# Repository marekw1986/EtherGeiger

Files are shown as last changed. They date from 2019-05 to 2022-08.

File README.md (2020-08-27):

# EtherGeiger

## Overview

This is firmware for Ethergeiger project, described on my [Hackaday.io profile](https://hackaday.io/project/163717-ethergeiger-20).

## Required Tools

Project was created in Microchip MPLAB X IDE.

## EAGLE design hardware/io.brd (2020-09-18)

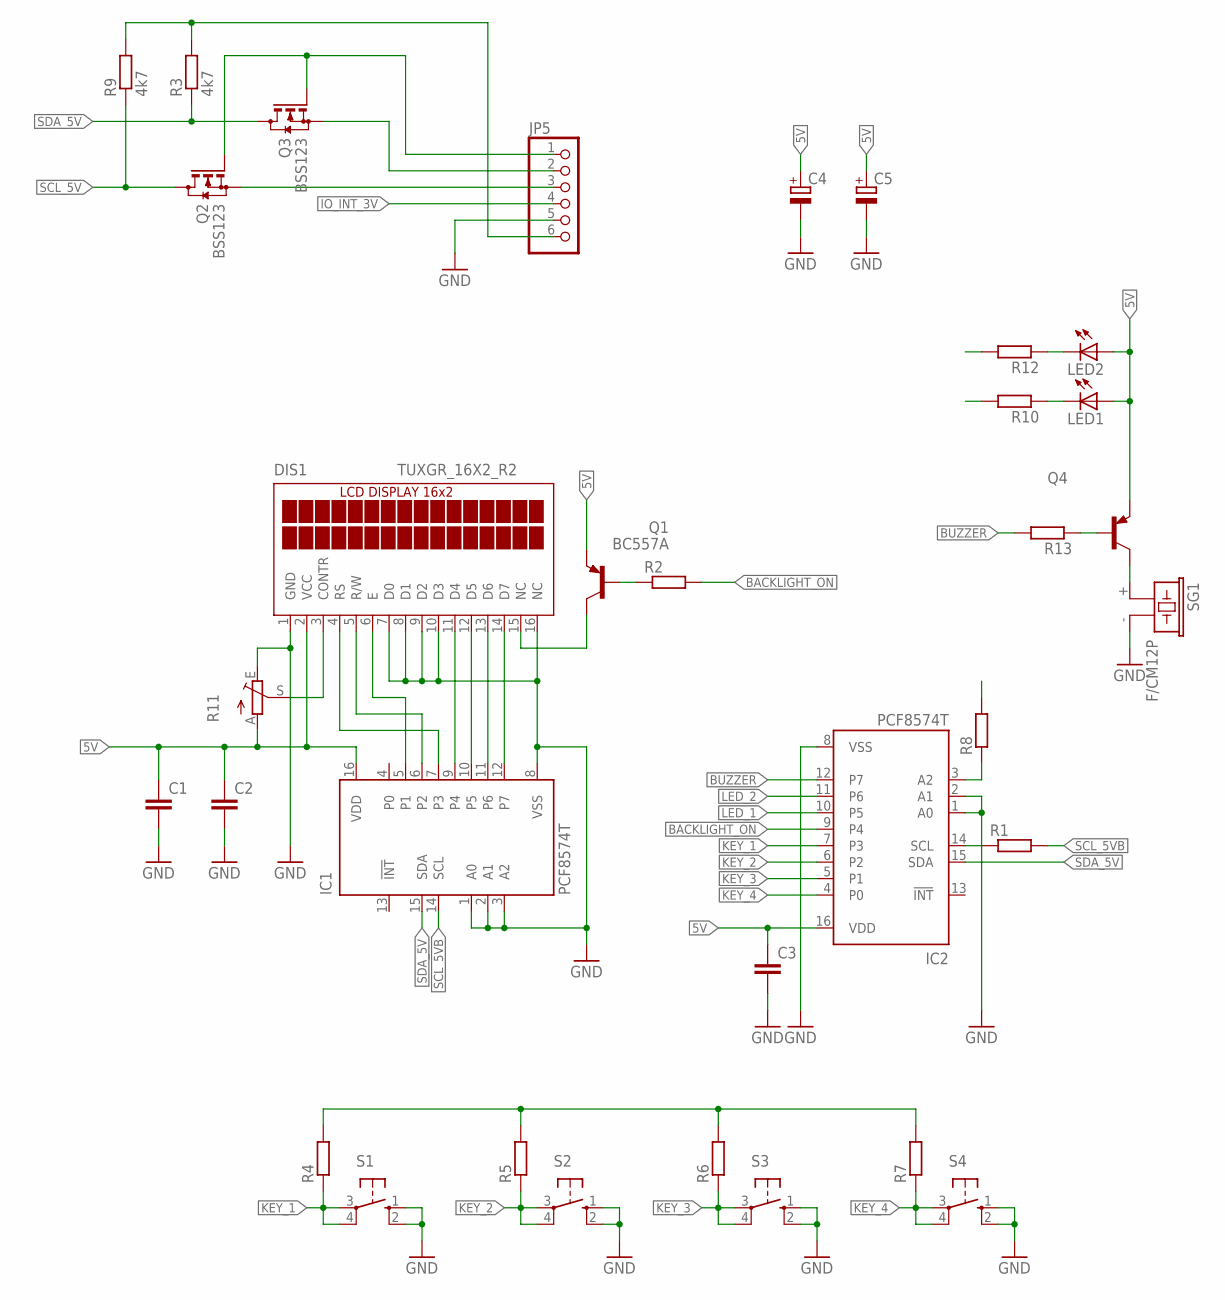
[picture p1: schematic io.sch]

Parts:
C1, C3: C-EUC1206; C1206
C2: C-EUC0603; C0603
C4, C5: CPOL-EUSMCD; SMC_D
DIS1: TUXGR_16X2_R2
IC1, IC2: PCF8574T; SO16W
JP5: PINHD-1X6; 1X06
LED1, LED2: LED5MM
Q1: BC557A; TO92-EBC
Q2, Q3: BSS123; SOT23
Q4: BC557A-PNP-TO92-EBC; TO92-EBC
R1, R8, R13: R-EU_R0603; R0603
R2, R6, R7, R10, R12: R-EU_0204/5; 0204/5
R3: 4k7; R0603
R4, R5: R-EU_0204/7; 0204/7
R9: 4k7; R1206
R11: TRIM_EU-B25U; B25U
S1, S2, S3, S4: 10-XX; B3F-10XX
SG1: F/CM12P

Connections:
5V: C1.1, C2.1, C3.1, C4.+, C5.+, DIS1.2 (VCC), IC1.16 (VDD), IC2.16 (VDD), JP5.6, LED1.A, LED2.A, Q1.E, Q4.E, R3.2, R4.2, R5.2, R6.2, R7.2, R8.2, R9.2, R11.A
BACKLIGHT_ON: IC2.9 (P4), R2.2
BUZZER: IC2.12 (P7), R13.2
GND: C1.2, C2.2, C3.2, C4.-, C5.-, DIS1.1 (GND), DIS1.7 (D0), DIS1.8 (D1), DIS1.9 (D2), DIS1.10 (D3), DIS1.16 (NC), IC1.1 (A0), IC1.2 (A1), IC1.3 (A2), IC1.8 (VSS), IC2.1 (A0), IC2.2 (A1), IC2.8 (VSS), JP5.5, R11.E, S1.1 (S), S1.2 (S1), S2.1 (S), S2.2 (S1), S3.1 (S), S3.2 (S1), S4.1 (S), S4.2 (S1), SG1.- (2)
IO_INT_3V: JP5.4
KEY_1: IC2.7 (P3), R4.1, S1.3, S1.4 (P1)
KEY_2: IC2.6 (P2), R5.1, S2.3, S2.4 (P1)
KEY_3: IC2.5 (P1), R6.1, S3.3, S3.4 (P1)
KEY_4: IC2.4 (P0), R7.1, S4.3, S4.4 (P1)
LED_1: IC2.10 (P5), R10.2
LED_2: IC2.11 (P6), R12.2
unnamed: DIS1.14 (D7), IC1.12 (P7)
unnamed: DIS1.13 (D6), IC1.11 (P6)
unnamed: DIS1.12 (D5), IC1.10 (P5)
unnamed: DIS1.11 (D4), IC1.9 (P4)
unnamed: DIS1.6 (E), IC1.5 (P1)
unnamed: DIS1.5 (R/W), IC1.6 (P2)
unnamed: DIS1.4 (RS), IC1.7 (P3)
unnamed: IC2.3 (A2), R8.1
unnamed: DIS1.15 (NC), Q1.C
unnamed: Q1.B, R2.1
unnamed: DIS1.3 (CONTR), R11.S
unnamed: LED1.K (C), R10.1
unnamed: LED2.K (C), R12.1
unnamed: Q4.C, SG1.+ (1)
unnamed: Q4.B, R13.1
SCL_3V: JP5.3, Q2.2 (S)
SCL_5V: IC2.14 (SCL), Q2.3 (D), R1.1, R9.1
SCL_5VB: IC1.14 (SCL), R1.2
SDA_3V: JP5.2, Q3.2 (S)
SDA_5V: IC1.15 (SDA), IC2.15 (SDA), Q3.3 (D), R3.1
_3V: JP5.1, Q2.1 (G), Q3.1 (G)

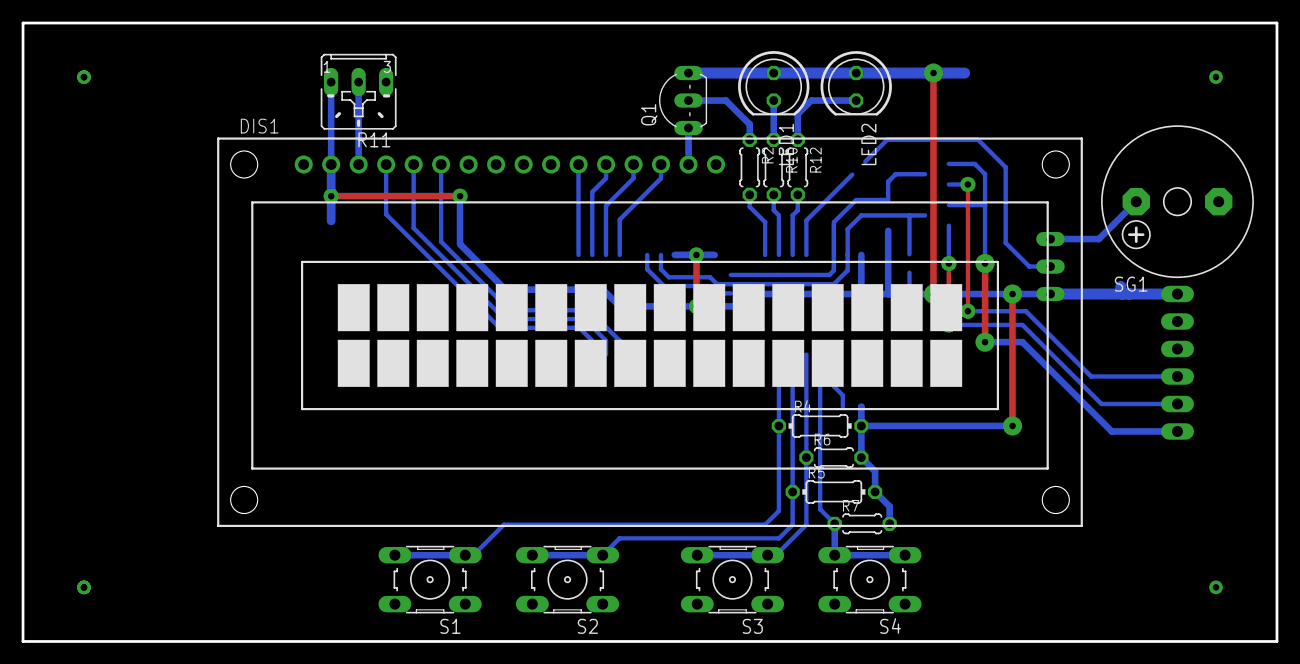
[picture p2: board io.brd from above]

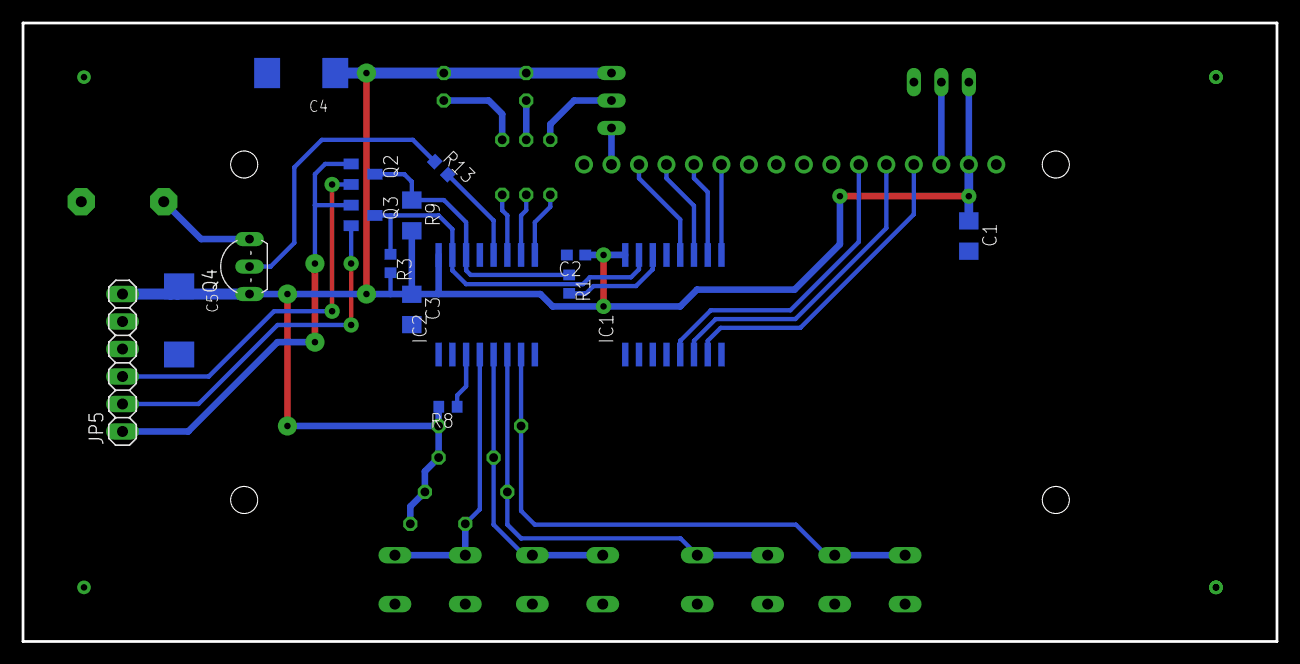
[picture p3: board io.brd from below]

Board: 2 copper layers, 115.9 x 57.1 mm, 33 parts (16 on the bottom side), 31 nets.

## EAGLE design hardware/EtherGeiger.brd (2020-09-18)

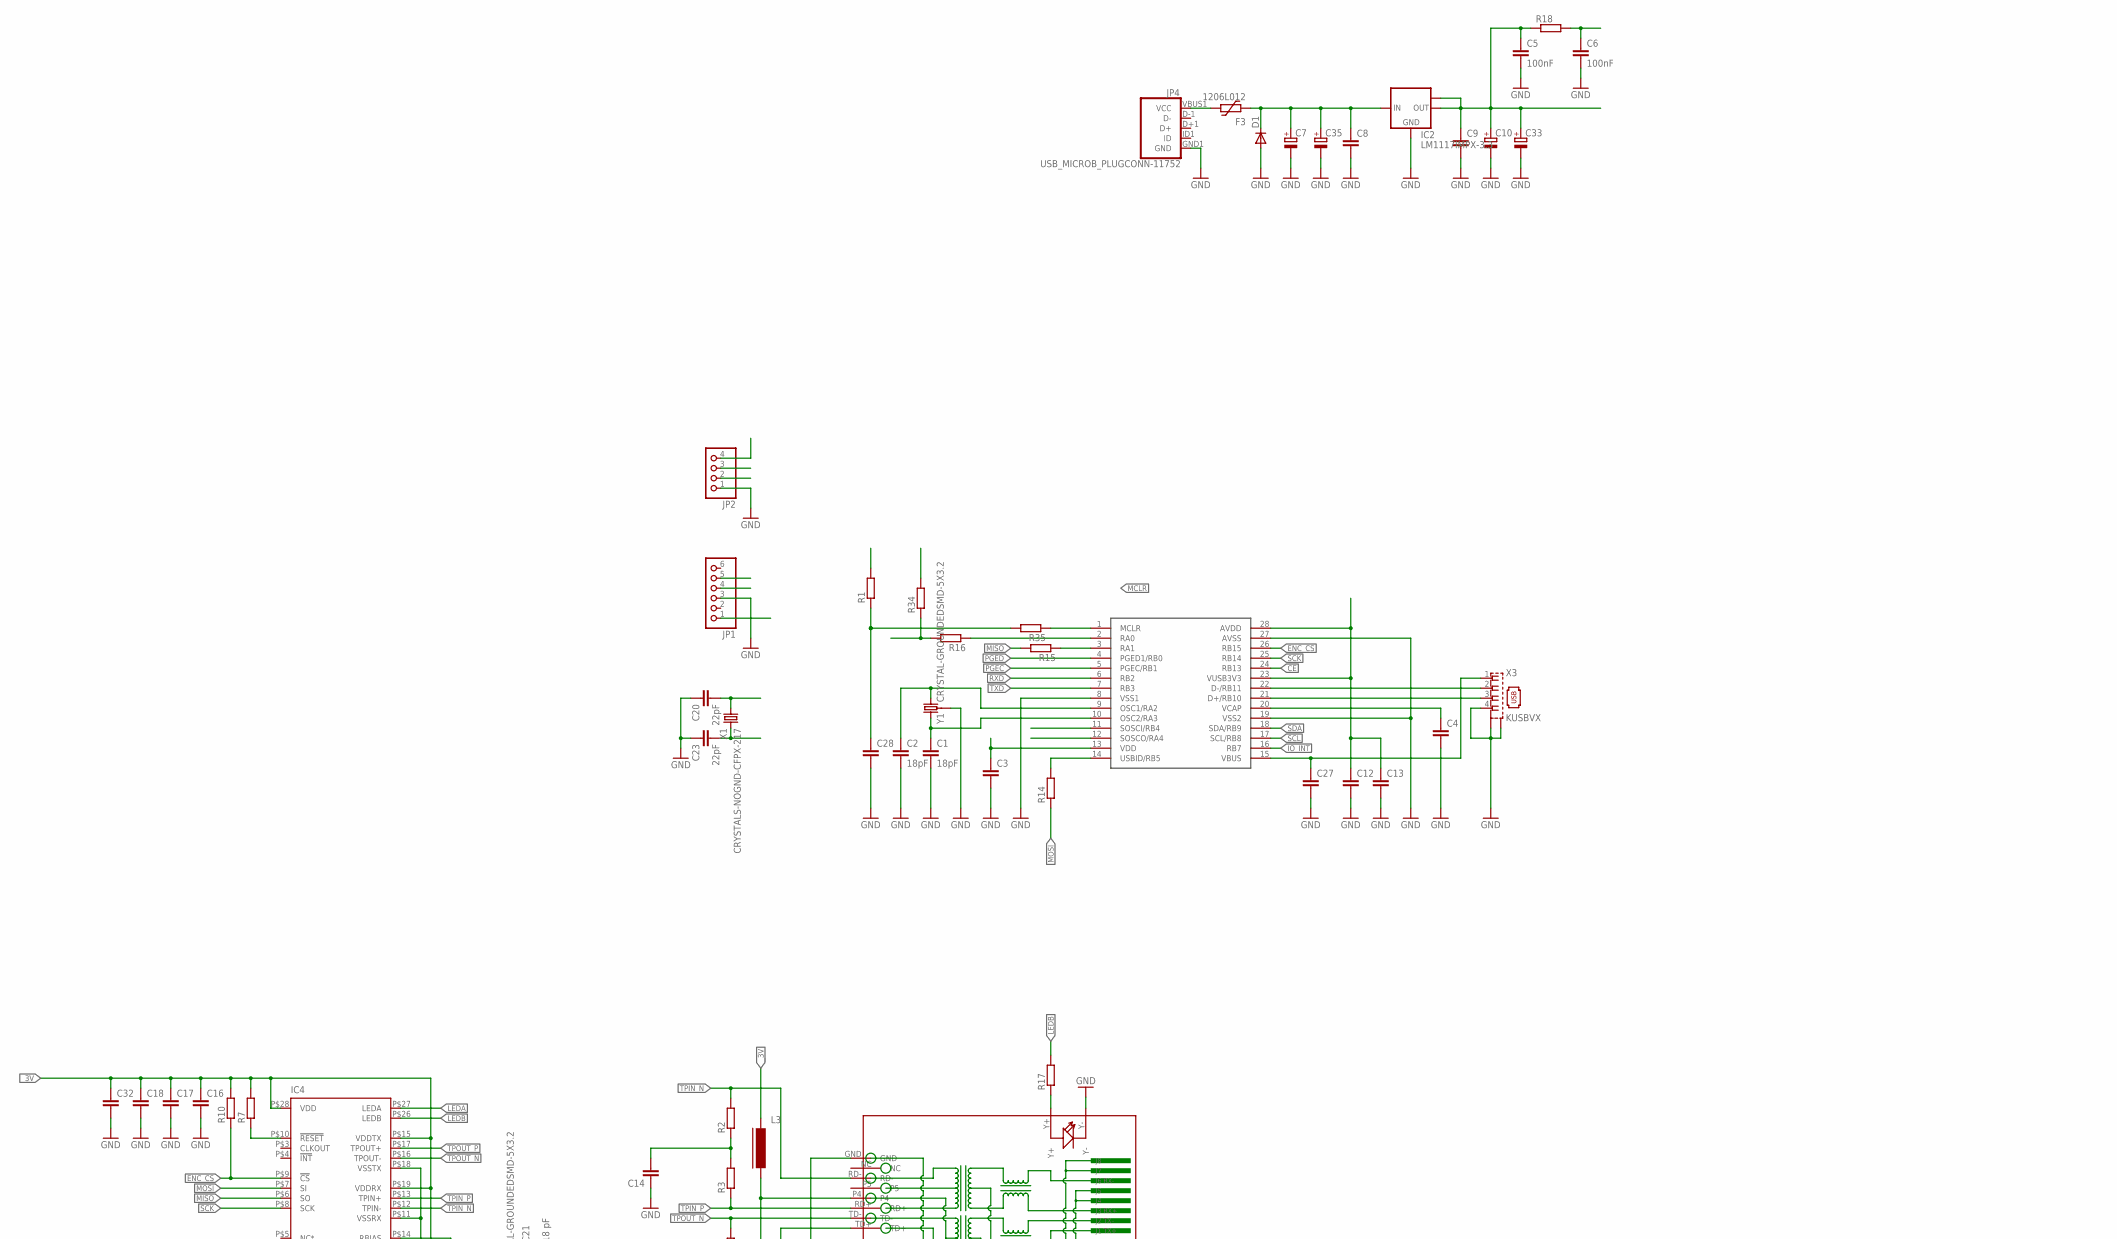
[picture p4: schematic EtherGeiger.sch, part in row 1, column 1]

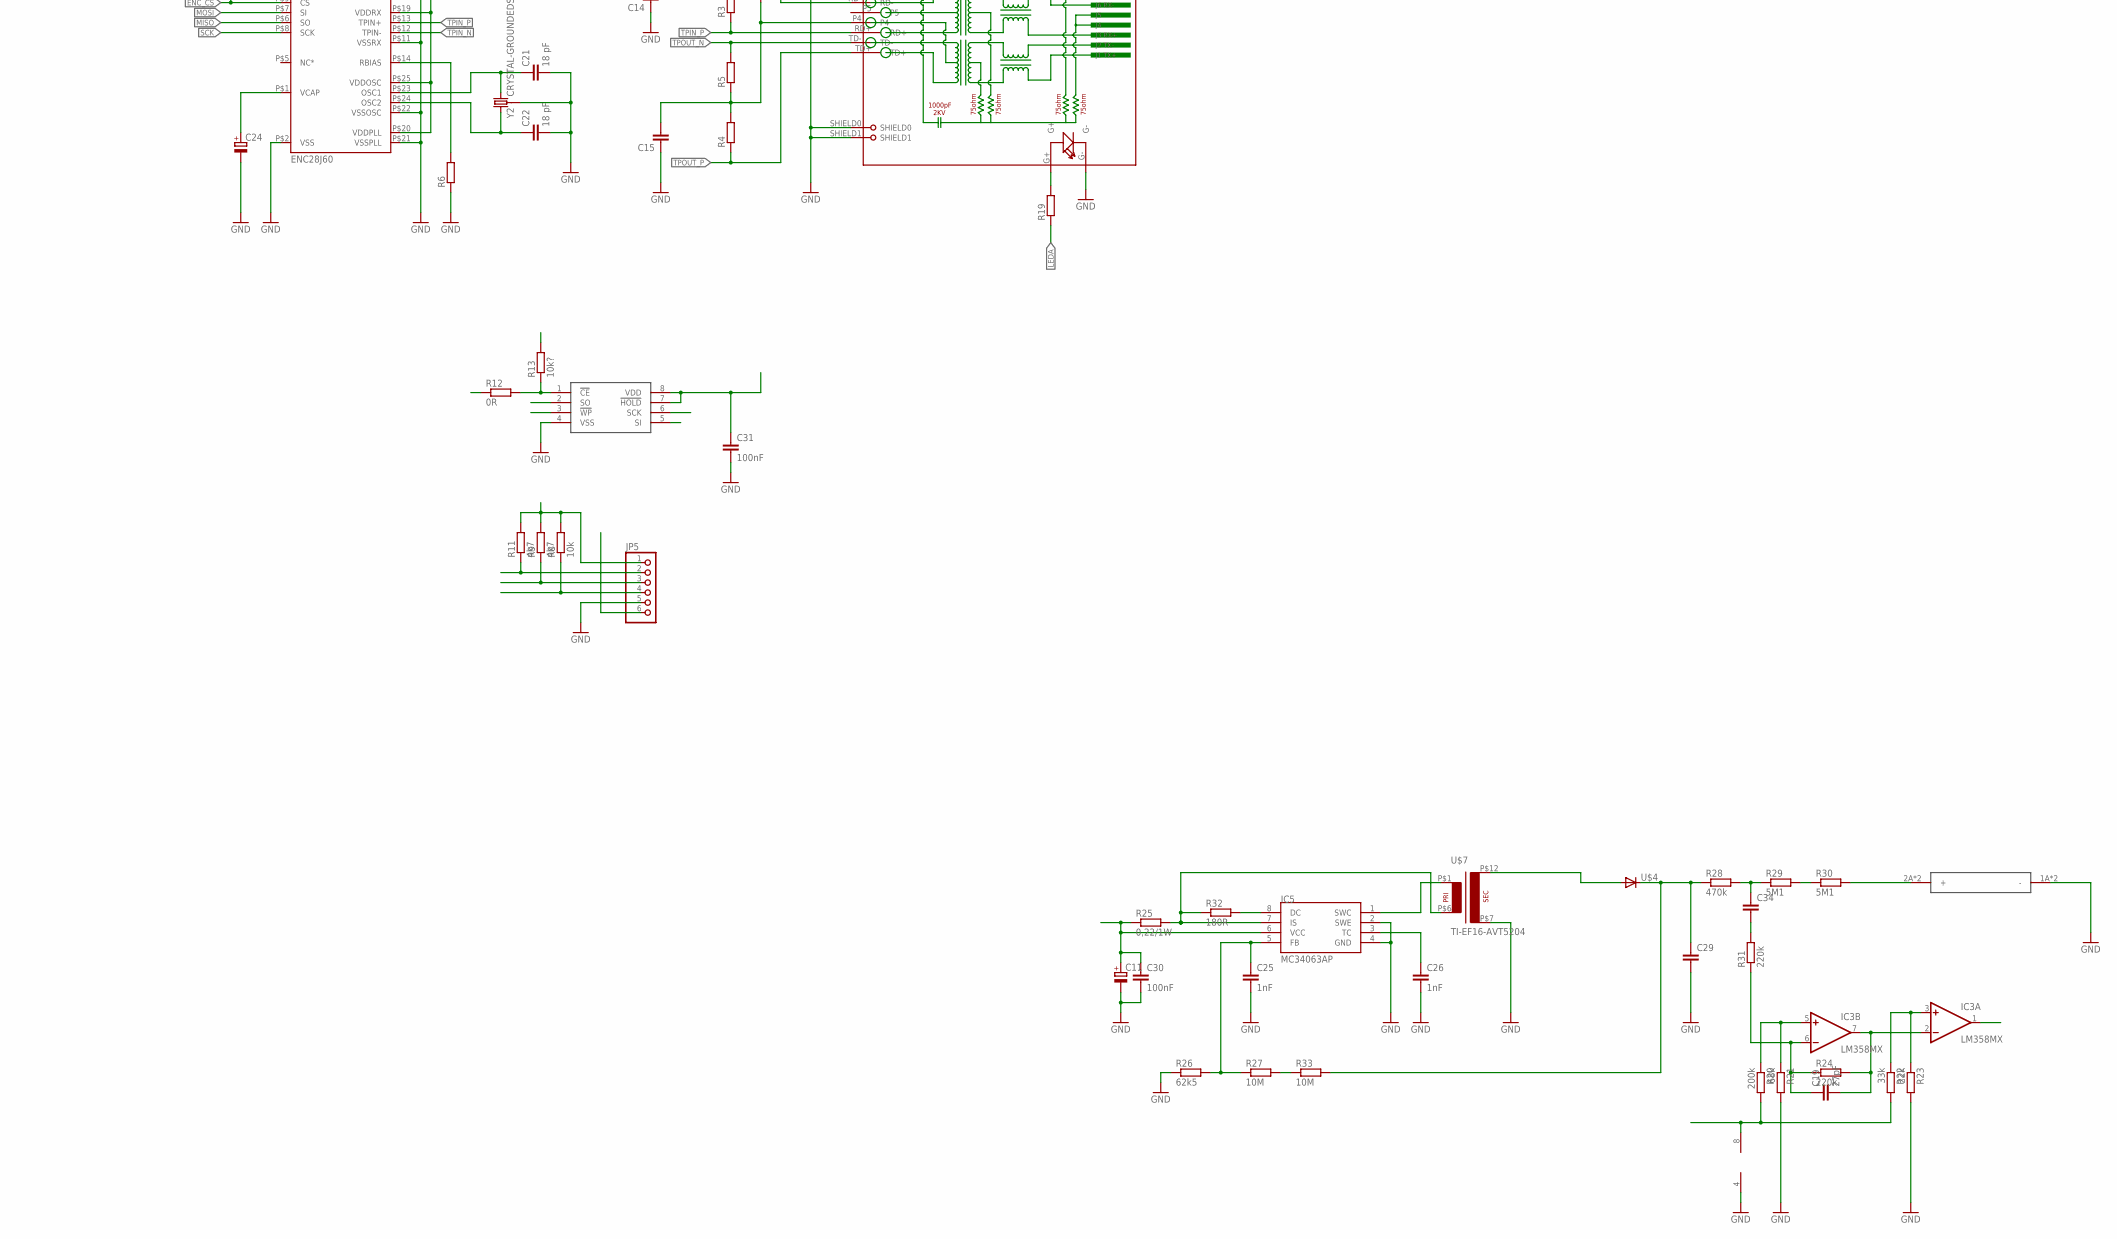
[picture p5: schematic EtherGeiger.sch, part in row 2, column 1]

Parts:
C1, C2: 18pF; C0603
C3, C12, C16, C32: C-EUC0402; C0402
C4, C8, C9, C13, C14, C15, C17, C18, C27, C28: C-EUC0603; C0603
C5, C6, C30, C31: 100nF; C0603
C7: CPOL-EUSMCC; SMC_C
C10: CPOL-EUSMCB; SMC_B
C11: CPOL-EUSMCE; SMC_E
C19: 27pF; C0603
C20, C23: 22pF; C0603
C21, C22: 18 pF; C0603
C24, C33, C35: CPOL-EUSMCA; SMC_A
C25, C26: 1nF; C0603
C29: C-EU225-113X268; C225-113X268
C34: C-EU050-024X044; C050-024X044
D1: DIODE-SMB; SMB
F3: 1206L012; 1206L
IC2: LM1117IMPX-3.3; SOT223
IC3: LM358MX; SO08
IC4: ENC28J60; TSSOP28W
IC5: MC34063AP; DIL08
JP1, JP5: PINHD-1X6; 1X06
JP2: PINHD-1X4; 1X04
JP4: USB_MICROB_PLUGCONN-11752; USB-B-MICRO-SMD_V03
L3: FERRITE-0805; FB805
R1, R2, R3, R4, R5, R7, R10, R14, R15, R34, R35: R-EU_R0603; R0603
R6: R-EU_R0805; R0805
R8: 10k; R0402
R9, R11: 4k7; R0402
R12: 0R; R0603
R13: 10k?; R0603
R16, R17, R18, R19: R-EU_R1206; R1206
R20: 200k; R0603
R21: 68k; R0603
R22: 33k; R0603
R23: 22k; R0603
R24: 220k; R0603
R25: 0,22/1W; R2010
R26: 62k5; R1206
R27, R33: 10M; R2512
R28: 470k; R2512
R29, R30: 5M1; R2512
R31: 220k; M1206
R32: 180R; R0805
RJ1: HR911105A
U$1: PIC32MX250F128B2; SSOP28
U$2: SST25VF016BSO8M; SO-08M
U$4: DIODE-MELF-MLL41; MELF-MLL41
U$5: STS5; GEIGERTUBE
U$7: TI-EF16-AVT5204; EF16-K-H-12P-12,5
X1: CRYSTALS-NOGND-CFPX-217; 3.2X1.5-2-PAD
X3: KUSBVX
Y1, Y2: CRYSTAL-GROUNDEDSMD-5X3.2; CRYSTAL-SMD-5X3.2-4PAD

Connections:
A_3V: C6.1, IC3.8 (V+), R18.2, R20.2, R22.2
CE: R12.1, U$1.24 (RB13)
CE1: R12.2, R13.1, U$2.1 (!CE)
CPM: IC3.1 (OUT), R16.2, R34.1
D_N: U$1.22 (D-/RB11), X3.2
D_P: U$1.21 (D+/RB10), X3.3
ENC_CS: IC4.P$9 (!CS), R10.1, U$1.26 (RB15)
ENC_RST: IC4.P$10 (!RESET), R7.1
GND: C1.2, C2.2, C3.2, C4.2, C5.2, C6.2, C7.-, C8.2, C9.2, C10.-, C11.-, C12.2, C13.2, C14.1, C15.1, C16.2, C17.2, C18.2, C20.1, C21.2, C22.2, C23.1, C24.-, C25.2, C26.2, C27.2, C28.2, C29.2, C30.2, C31.2, C32.2, C33.-, C35.-, D1.A, IC2.1 (GND), IC3.4 (V-), IC4.P$2 (VSS), IC4.P$11 (VSSRX), IC4.P$18 (VSSTX), IC4.P$21 (VSSPLL), IC4.P$22 (VSSOSC), IC5.2 (SWE), IC5.4 (GND), JP1.3, JP2.1, JP4.GND1 (GND), JP5.5, R6.1, R21.2, R23.2, R26.1, RJ1.G-, RJ1.GND, RJ1.SHIELD0, RJ1.SHIELD1, RJ1.Y-, U$1.8 (VSS1), U$1.19 (VSS2), U$1.27 (AVSS), U$2.4 (VSS), U$5.1A (-), U$5.1B (-), U$7.P$7 (P7), X3.4, X3.M1 (S1), X3.M2 (S2), Y1.2 (3), Y1.4 (3), Y2.2 (3), Y2.4 (3)
HV: C29.1, R28.1, R33.2, U$4.C
IO_INT: JP5.4, R8.1, U$1.16 (RB7)
LEDA: IC4.P$27 (LEDA), R19.1
LEDB: IC4.P$26 (LEDB), R17.2
MCLR: JP1.1, R35.1, U$1.1 (MCLR)
MISO: IC4.P$6 (SO), R15.2, U$2.2 (SO)
MOSI: IC4.P$7 (SI), R14.1, U$2.5 (SI)
unnamed: C14.2, R2.1, R3.2
unnamed: IC5.7 (IS), R25.2, R32.1, U$7.P$6 (P6)
unnamed: C19.1, IC3.6 (-IN), R24.1, R31.1
unnamed: C15.2, L3.2, R4.2, R5.1, RJ1.P4
unnamed: C4.1, U$1.20 (VCAP)
unnamed: C19.2, IC3.2 (-IN), IC3.7 (OUT), R24.2
unnamed: C26.1, IC5.3 (TC)
unnamed: IC4.P$14 (RBIAS), R6.2
unnamed: R14.2, U$1.14 (USBID/RB5)
unnamed: F3.1, JP4.VBUS1 (VCC)
unnamed: R15.1, U$1.3 (RA1)
unnamed: R16.1, U$1.2 (RA0)
unnamed: C1.1, U$1.10 (OSC2/RA3), Y1.3 (1)
unnamed: C2.1, U$1.9 (OSC1/RA2), Y1.1 (2)
unnamed: IC3.5 (+IN), R20.1, R21.1
unnamed: IC3.3 (+IN), R22.1, R23.1
unnamed: U$4.A, U$7.P$12 (P12)
unnamed: C21.1, IC4.P$23 (OSC1), Y2.1 (2)
unnamed: C22.1, IC4.P$24 (OSC2), Y2.3 (1)
unnamed: C25.1, IC5.5 (FB), R26.2, R27.1
unnamed: R30.2, U$5.2A (+), U$5.2B (+)
unnamed: R29.2, R30.1
unnamed: C34.1, R28.2, R29.1
unnamed: C34.2, R31.2
unnamed: C24.+, IC4.P$1 (VCAP)
unnamed: R17.1, RJ1.Y+
unnamed: R19.2, RJ1.G+
unnamed: IC5.1 (SWC), U$7.P$1 (P1)
unnamed: IC5.8 (DC), R32.2
unnamed: R27.2, R33.1
PGEC: JP1.5, U$1.5 (PGEC/RB1)
PGED: JP1.4, U$1.4 (PGED1/RB0)
RXD: JP2.3, U$1.6 (RB2)
SCK: IC4.P$8 (SCK), U$1.25 (RB14), U$2.6 (SCK)
SCL: JP5.3, R9.1, U$1.17 (SCL/RB8)
SDA: JP5.2, R11.1, U$1.18 (SDA/RB9)
SOSCI: C20.2, U$1.11 (SOSCI/RB4), X1.1
SOSCO: C23.2, U$1.12 (SOSCO/RA4), X1.2
TPIN_N: IC4.P$12 (TPIN-), R2.2, RJ1.RD-
TPIN_P: IC4.P$13 (TPIN+), R3.1, RJ1.RD+
TPOUT_N: IC4.P$16 (TPOUT-), R5.2, RJ1.TD-
TPOUT_P: IC4.P$17 (TPOUT+), R4.1, RJ1.TD+
TXD: JP2.2, U$1.7 (RB3)
VBUS: C7.+, C8.1, C11.+, C27.1, C30.1, C35.+, D1.C, F3.2, IC2.3 (IN), IC5.6 (VCC), JP5.6, R25.1, U$1.15 (VBUS), X3.1
_3V: C3.1, C5.1, C9.1, C10.+, C12.1, C13.1, C16.1, C17.1, C18.1, C31.1, C32.1, C33.+, IC2.2 (OUT), IC2.TAB (OUT1), IC4.P$15 (VDDTX), IC4.P$19 (VDDRX), IC4.P$20 (VDDPLL), IC4.P$25 (VDDOSC), IC4.P$28 (VDD), JP2.4, JP5.1, L3.1, R1.2, R7.2, R8.2, R9.2, R10.2, R11.2, R13.2, R18.1, R34.2, U$1.13 (VDD), U$1.23 (VUSB3V3), U$1.28 (AVDD), U$2.3 (!WP), U$2.7 (!HOLD), U$2.8 (VDD)
_MCLR: C28.1, R1.1, R35.2

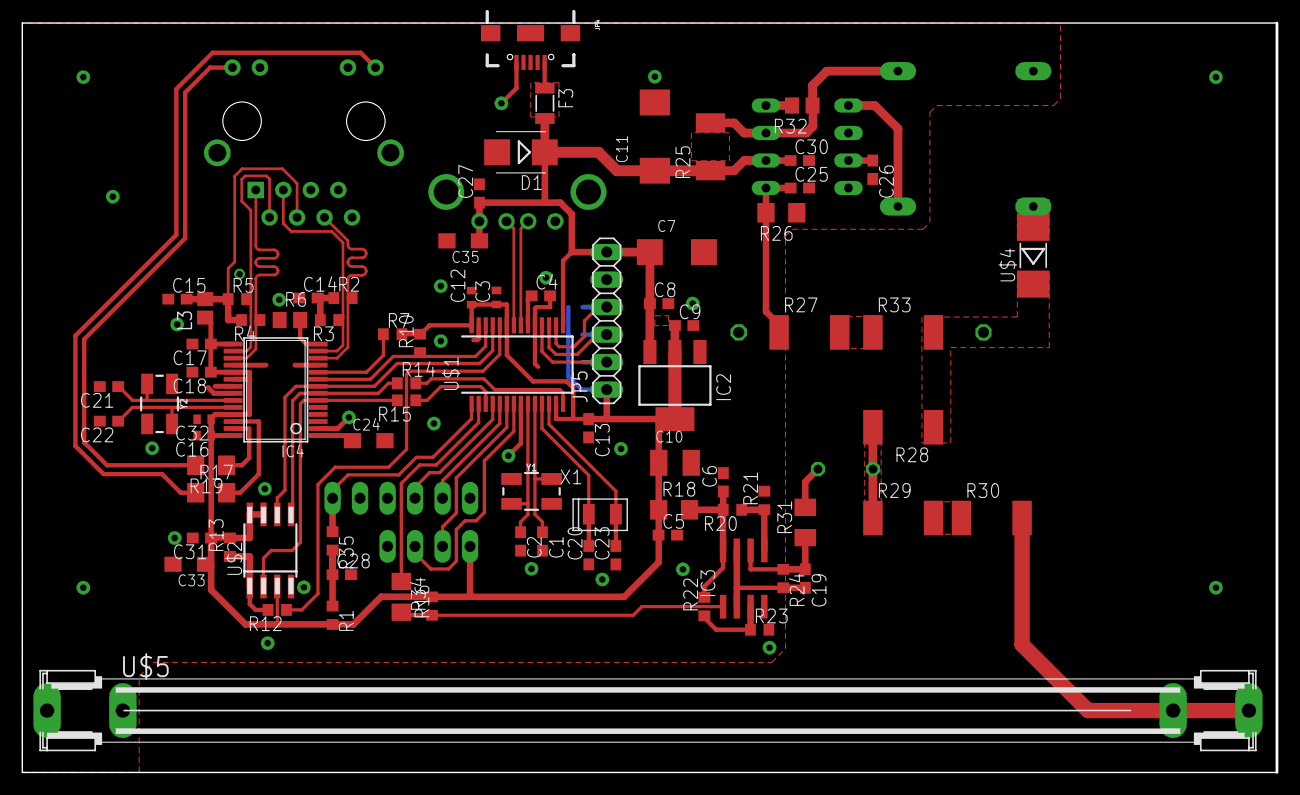
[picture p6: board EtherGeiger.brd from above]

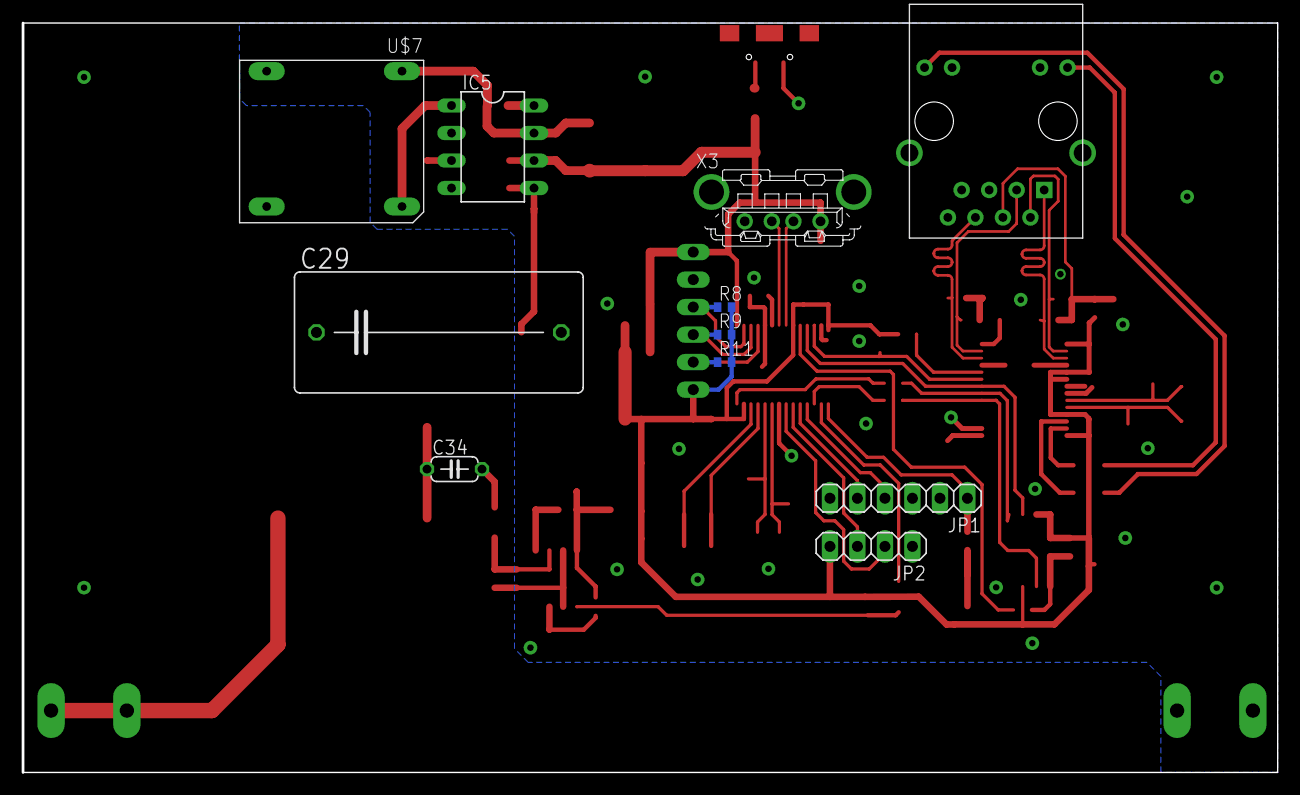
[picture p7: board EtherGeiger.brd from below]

Board: 2 copper layers, 115.9 x 69.2 mm, 91 parts (11 on the bottom side), 62 nets.

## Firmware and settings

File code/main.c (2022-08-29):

/* 
 * File:   main.c
 * Author: Marek
 *
 * Created on 7 stycznia 2016, 12:22
 */

#include <xc.h>
#include <stdio.h>
#include <stdlib.h>
#include <stdint.h>
#include <p32xxxx.h>
#include <plib.h>
#include <time.h>
#include <string.h>

#include "delay/delay.h"
#include "time/time.h"
#include "uart/uart.h"
#include "common.h"
#include "usb_host_msd/usb.h"
#include "usb_host_msd/usb_host_msd.h"
#include "usb_host_msd/usb_host_msd_scsi.h"
#include "fatfs/ff.h"
#include "fatfs/diskio.h"
#include "net/TCPIP.h"
#include "net/MQTT.h"
#include "nvram/nvram.h"
#include "config/config.h"
#include "geiger/geiger.h"
#include "HardwareProfile.h"
#include "lcd/i2c.h"
#include "lcd/hd44780.h"
#include "bme280/bme280.h"


#pragma config JTAGEN = OFF        // Disable JTAG
#pragma config FSOSCEN = ON        // ENABLE secondary oscillator

#pragma config POSCMOD=HS          // High speed crystal mode
#pragma config FNOSC=PRIPLL        // Use Primary Oscillator with PLL (XT, HS, or EC) 
#pragma config FPLLIDIV=DIV_2      // Divide 8MHz to between 4-5MHz before PLL (now 4MHz)
#pragma config FPLLMUL=MUL_20      // Multiply with PLL (now 80MHz)
#pragma config FPLLODIV=DIV_2      // Divide After PLL (now 40 MHz)

#pragma config FWDTEN = ON         // Enable watchdog timer
#pragma config WDTPS = PS4096
#pragma config ICESEL = ICS_PGx1   // select pins to transfer program data on (ICSP pins)

#pragma config FVBUSONIO = OFF
#pragma config FUSBIDIO = OFF
#pragma config UPLLEN   = ON
#pragma config UPLLIDIV = DIV_2

char buffer[128];
FATFS SPIFatFS;
FATFS USBFatFS;

extern void GenericTCPServer(void);
static void handle_usb_log (void);
static void handle_bme_read (void);
//void handle_mqtt(void);
char* constructJSON (char* buf, uint16_t len);
void mqtt_init (void);
void handle_mqtt_log(void);
void mqtt_on_connect(void);
void mqtt_on_publish(void);
void mqtt_on_subscribe(void);
void mqtt_on_receive(const char *topic, const WORD topicLength, const BYTE *payload, const WORD payloadLength);

int main(int argc, char** argv) {
    
    FRESULT res;
    uint32_t disk_timer, wdt_timer;
    uint8_t io;
    
    DisableWDT();
    SYSTEMConfigPerformance(SYSCLK);
    
    __XC_UART = 1;
    
    ANSELA = 0;
    ANSELB = 0;
    TRISBbits.TRISB15 = 0;      //ENC28J60 CS
    
    SDI1Rbits.SDI1R = 0b0000; 	//SDI1 is RPA1
    RPB5Rbits.RPB5R = 0b0011; 	//SDO1 is RPB5 (RB14 is hardwired as SCK1)
    T2CKRbits.T2CKR = 0b0000;   //T2CK is RPA0;
    TRISAbits.TRISA0 = 1;       //RA0 (T2CK) is input
    TRISAbits.TRISA1 = 1; 		//RA1 (SDI1) is input
    TRISBbits.TRISB5 = 0; 		//RB5 (SDO1) is output
    TRISBbits.TRISB14 = 0; 		//RB14 (SCK1) is output
    
    memset(buffer, 0x00, sizeof(buffer));
 
    time_init();
    MPFSInit();
    TickInit();
    uart_init();
    i2c_init();
    lcd_init();
    bme_init();
    bme_setup();
    INTEnableSystemMultiVectoredInt();
    
    USBInitialize(0);
//    while(!USBHostMSDSCSIMediaDetect()) {
//        USBTasks(); //wait   for usb attach
//        //tutuaj trzeba zaimplentowac timout oczekiwania na mediadetect()
//    }
    
    res = f_mount(&SPIFatFS, "0:", 1);
    if (res != FR_OK) {printf("f_mount error code: %i\r\n", res);}
    else {printf("f_mount OK\r\n");}
    
    res = f_mount(&USBFatFS, "1:", 0);
    if (res != FR_OK) {printf("f_mount error code: %i\r\n", res);}
    else {printf("f_mount OK\r\n");}
    
    CheckAndLoadDefaults();
    StackInit();
    
    geiger_init();
    
    ClearWDT();
    EnableWDT();
    
    i2c_send_byte(0xFF, PCF8574_IO_ADDR);
    init_ui();
    
    MQTTSetConnectCallback(mqtt_on_connect);
    MQTTSetReceiveCallback(mqtt_on_receive);
    mqtt_init();
    
    while (1) {
        
        StackTask();
        StackApplications();
        UART_RX_STR_EVENT(buffer);
        //GenericTCPServer();
        
        USBTasks();
        if ((uint32_t)(millis()-disk_timer) >= 10) {
            disk_timer = millis();
            disk_timerproc();
        }
        
        if ((uint32_t)(millis()-wdt_timer) >= 300) {
            wdt_timer = millis();
            ClearWDT();
//            io = i2c_rcv_byte(PCF8574_IO_ADDR);
//            io ^= 0x60;
//            i2c_send_byte(io, PCF8574_IO_ADDR);
        }        
        
        handle_bme_read();
        handle_ui();
        lcd_handle();
        handle_usb_log();
        handle_mqtt_log();
    }

    return (EXIT_SUCCESS);
}


void handle_bme_read (void) {
    static uint32_t bme_timer = 0;
    
    if ( (uint32_t)(millis()-bme_timer) > 20000 ) {
        bme_read_temp_press_and_hum();
        bme_temperature = bme_get_temperature();
        bme_pressure = bme_get_pressure(); //value in hPa
        bme_humidity = bme_get_humidity() * 100; //value in percents
        bme_timestamp = rtccGetTimestamp();
        bme_timer = millis();
    }
}


void find_latest_file (char *path) {
    FRESULT res;
    DIR dir;
    static FILINFO fno;
    uint16_t i;
    uint32_t file_id = 0;
    uint32_t max_file_id= 0;
    
    res = f_opendir(&dir, path);
    if (res == FR_OK) {
        for (;;) {
            res = f_readdir(&dir, &fno);
            if (res != FR_OK || fno.fname[0] == 0) break;
            if (!(fno.fattrib & AM_DIR)) { /* It is not a directory */
                if (sscanf(fno.fname, "geiger%lu.csv", &file_id) != 1) break;
                if (file_id > max_file_id) max_file_id = file_id;
                printf("%s/%s\n", path, fno.fname);
            }                    
        }
        f_closedir(&dir);
    }
}


void handle_usb_log (void) {
    
    static uint32_t timer = 0;
    FRESULT res;
    FIL file;
    time_t tm;
	uint16_t countspm;
    double siv;
    char temp[100];
    
    if ( (config.usbLogInterval != 0) && ((uint32_t)(uptime()-timer) >= config.usbLogInterval) ) {
        timer = uptime();
        
        if ( (uptime() > 60) && rtccIsSet() ) {
            res = f_open(&file, "1:/geiger.csv", (FA_OPEN_ALWAYS | FA_WRITE));
            if (res != FR_OK) {
                printf("f_open error code: %i\r\n", res);
                return;
            }
            if (f_size(&file) == 0) {
                f_puts("Time (UTC);CPM;uSv/h\r\n", &file);
            }
            else {
                res = f_lseek(&file, f_size(&file));
                if (res != FR_OK) {
                    printf("f_lseek error code: %i\r\n", res); 
                    f_close(&file);
                    return;
                }
            }
            countspm = cpm();
            siv = cpm2sievert(countspm);
            tm = rtccGetTimestamp();
            strncpy(temp, asctime(gmtime(&tm)), sizeof(temp)-1);
            strtok(temp, "\n");
            f_puts(temp, &file);
            f_putc(';', &file);
            sprintf(temp, "%d", countspm);
            f_puts(temp, &file);
            f_putc(';', &file);
            sprintf(temp, "%.4f\r\n", siv);
            f_puts(temp, &file);
            f_close(&file);            
        }
    }   
}

void mqtt_init (void) {
    if(MQTTBeginUsage()) {
        printf("Starting MQTT\r\n");
        MQTTClient.Server.szRAM = config.mqtt_server;	// MQTT server address
        MQTTClient.ServerPort = 1883;
        MQTTClient.ConnectId.szRAM = "d:atlantis:ethergeiger:1";
        MQTTClient.Topic.szRAM = config.mqtt_topic;
        MQTTClient.Username.szRAM = config.mqtt_username;
        MQTTClient.Password.szRAM = config.mqtt_password;                
        MQTTClient.bSecure=FALSE;
        MQTTClient.QOS=1;
        MQTTClient.KeepAlive=MQTT_KEEPALIVE_LONG;   
    }
}

void mqtt_on_connect(void) {
    printf("MQTT connected\r\n");
    //MQTTSubscribe("testTopic", mqtt_on_subscribe);
    //MQTTSendStr("testTopic", "Hellord!", NULL);
}

void mqtt_on_publish(void) {
    printf("MQTT published\r\n");
    mqtt_last_publish = uptime();  //TODO
}

void mqtt_on_subscribe(void) {
    printf("MQTT subscribed\r\n");
}

void mqtt_on_receive(const char *topic, const WORD topicLength, const BYTE *payload, const WORD payloadLength) {
    char tmp[512];
    memcpy(tmp, topic, topicLength);
    tmp[topicLength] = '\0';
    printf("Received topic: %s\r\n", tmp);
    memcpy(tmp, payload, payloadLength);
    tmp[payloadLength] = '\0';
    printf("Received payload:\r\n%s\r\n", tmp);
    printf("Payload len: %d\r\n", payloadLength);
}

void handle_mqtt_log(void) {
    static uint32_t timer = 0;
    static char JSONBuffer[512];
    
    if ( ((uint32_t)(uptime()-timer) >= 30) && (uptime() > 60) ) {
        constructJSON(JSONBuffer, sizeof(JSONBuffer)-2);
        MQTTSendStr(config.mqtt_topic, JSONBuffer, mqtt_on_publish);
        timer = uptime();
    }
}


static enum {
      EXCEP_IRQ = 0,            // interrupt
      EXCEP_AdEL = 4,            // address error exception (load or ifetch)
      EXCEP_AdES,                // address error exception (store)
      EXCEP_IBE,                // bus error (ifetch)
      EXCEP_DBE,                // bus error (load/store)
      EXCEP_Sys,                // syscall
      EXCEP_Bp,                // breakpoint
      EXCEP_RI,                // reserved instruction
      EXCEP_CpU,                // coprocessor unusable
      EXCEP_Overflow,            // arithmetic overflow
      EXCEP_Trap,                // trap (possible divide by zero)
      EXCEP_IS1 = 16,            // implementation specfic 1
      EXCEP_CEU,                // CorExtend Unuseable
      EXCEP_C2E                // coprocessor 2
  } _excep_code;


static unsigned int _epc_code;
static unsigned int _excep_addr;



void _general_exception_handler(void) {
    int i=0;
    asm volatile("mfc0 %0,$13" : "=r" (_excep_code));
    asm volatile("mfc0 %0,$14" : "=r" (_excep_addr));
  
    _excep_code = (_excep_code & 0x0000007C) >> 2;
 

	 printf("\r\n\r\n GE at %x ",_excep_addr);
	 switch(_excep_code){
        case EXCEP_IRQ: printf("interrupt");break;
        case EXCEP_AdEL: printf("address error exception (load or ifetch)");break;
        case EXCEP_AdES: printf("address error exception (store)");break;
        case EXCEP_IBE: printf("(ifetch)");break; //bus error
        case EXCEP_DBE: printf("(load/store)");break; //bus error
        case EXCEP_Sys: printf("syscall");break;
        case EXCEP_Bp: printf("breakpoint");break;
        case EXCEP_RI: printf("reserved instruction");break;
        case EXCEP_CpU: printf("coprocessor unusable");break;
        case EXCEP_Overflow: printf("arithmetic overflow");break;
        case EXCEP_Trap: printf("trap (possible divide by zero)");break;
        case EXCEP_IS1: printf("implementation specfic 1");break;
        case EXCEP_CEU: printf("CorExtend Unuseable");break;
        case EXCEP_C2E: printf("coprocessor 2");break;
      }
	  printf("\r\nExecution halted.\r\n");
      while (1) {
		printf("Waiting for WTD reset %lu\r\n",i++);
		delay_ms(1000);
      }
}

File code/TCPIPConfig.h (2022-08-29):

/*********************************************************************
 *
 *	Microchip TCP/IP Stack Demo Application Configuration Header
 *
 *********************************************************************
 * FileName:        TCPIPConfig.h
 * Dependencies:    Microchip TCP/IP Stack
 * Processor:       PIC18, PIC24F, PIC24H, dsPIC30F, dsPIC33F, PIC32
 * Compiler:        Microchip C32 v1.10 or higher
 *					Microchip C30 v3.12 or higher
 *					Microchip C18 v3.34 or higher
 *					HI-TECH PICC-18 PRO 9.63PL2 or higher
 * Company:         Microchip Technology, Inc.
 *
 * Software License Agreement
 *
 * Copyright (C) 2002-2010 Microchip Technology Inc.  All rights
 * reserved.
 *
 * Microchip licenses to you the right to use, modify, copy, and
 * distribute:
 * (i)  the Software when embedded on a Microchip microcontroller or
 *      digital signal controller product ("Device") which is
 *      integrated into Licensee's product; or
 * (ii) ONLY the Software driver source files ENC28J60.c, ENC28J60.h,
 *		ENCX24J600.c and ENCX24J600.h ported to a non-Microchip device
 *		used in conjunction with a Microchip ethernet controller for
 *		the sole purpose of interfacing with the ethernet controller.
 *
 * You should refer to the license agreement accompanying this
 * Software for additional information regarding your rights and
 * obligations.
 *
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
 *
 * V5.36   ---- STACK_USE_MPFS support has been removed 
 ********************************************************************/
#ifndef __TCPIPCONFIG_H
#define __TCPIPCONFIG_H

#include "GenericTypeDefs.h"
#include "Compiler.h"
#define GENERATED_BY_TCPIPCONFIG "Version 1.0.4612.18258"

// =======================================================================
//   Application Options
// =======================================================================

/* Application Level Module Selection
 *   Uncomment or comment the following lines to enable or
 *   disabled the following high-level application modules.
 */
//#define STACK_USE_UART					// Application demo using UART for IP address display and stack configuration
//#define STACK_USE_UART2TCP_BRIDGE		// UART to TCP Bridge application example
//#define STACK_USE_IP_GLEANING
#define STACK_USE_ICMP_SERVER			// Ping query and response capability
//#define STACK_USE_ICMP_CLIENT			// Ping transmission capability
#define STACK_USE_HTTP2_SERVER			// New HTTP server with POST, Cookies, Authentication, etc.
//#define STACK_USE_SSL_SERVER			// SSL server socket support (Requires SW300052)
//#define STACK_USE_SSL_CLIENT			// SSL client socket support (Requires SW300052)
//#define STACK_USE_AUTO_IP               // Dynamic link-layer IP address automatic configuration protocol
#define STACK_USE_DHCP_CLIENT			// Dynamic Host Configuration Protocol client for obtaining IP address and other parameters
//#define STACK_USE_DHCP_SERVER			// Single host DHCP server
//#define STACK_USE_FTP_SERVER			// File Transfer Protocol (old)
//#define STACK_USE_SMTP_CLIENT			// Simple Mail Transfer Protocol for sending email
//#define STACK_USE_SNMP_SERVER			// Simple Network Management Protocol v2C Community Agent
//#define STACK_USE_SNMPV3_SERVER			// Simple Network Management Protocol v3 Agent
//#define STACK_USE_TFTP_CLIENT			// Trivial File Transfer Protocol client
//#define STACK_USE_GENERIC_TCP_CLIENT_EXAMPLE	// HTTP Client example in GenericTCPClient.c
//#define STACK_USE_GENERIC_TCP_SERVER_EXAMPLE	// ToUpper server example in GenericTCPServer.c
//#define STACK_USE_TELNET_SERVER			// Telnet server
//#define STACK_USE_ANNOUNCE				// Microchip Embedded Ethernet Device Discoverer server/client
#define STACK_USE_DNS					// Domain Name Service Client for resolving hostname strings to IP addresses
//#define STACK_USE_DNS_SERVER			// Domain Name Service Server for redirection to the local device
//#define STACK_USE_NBNS					// NetBIOS Name Service Server for repsonding to NBNS hostname broadcast queries
//#define STACK_USE_REBOOT_SERVER			// Module for resetting this PIC remotely.  Primarily useful for a Bootloader.
#define STACK_USE_SNTP_CLIENT			// Simple Network Time Protocol for obtaining current date/time from Internet
//#define STACK_USE_UDP_PERFORMANCE_TEST	// Module for testing UDP TX performance characteristics.  NOTE: Enabling this will cause a huge amount of UDP broadcast packets to flood your network on the discard port.  Use care when enabling this on production networks, especially with VPNs (could tunnel broadcast traffic across a limited bandwidth connection).
//#define STACK_USE_TCP_PERFORMANCE_TEST	// Module for testing TCP TX performance characteristics
//#define STACK_USE_DYNAMICDNS_CLIENT		// Dynamic DNS client updater module
//#define STACK_USE_BERKELEY_API			// Berekely Sockets APIs are available
//#define STACK_USE_ZEROCONF_LINK_LOCAL	// Zeroconf IPv4 Link-Local Addressing
//#define STACK_USE_ZEROCONF_MDNS_SD		// Zeroconf mDNS and mDNS service discovery
#define STACK_USE_MQTT_CLIENT
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

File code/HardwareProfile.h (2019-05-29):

/* 
 * File:   HardwareProfile.h
 * Author: Marek
 *
 * Created on 7 stycznia 2016, 18:25
 */

#ifndef HARDWAREPROFILE_H
#define	HARDWAREPROFILE_H

#ifdef	__cplusplus
extern "C" {
#endif
    
#define SystemClock             (40000000ul)

#define GetSystemClock()        SystemClock
#define GetInstructionClock()   SystemClock
#define GetPeripheralClock()    (SystemClock/(1<<OSCCONbits.PBDIV))

#define CP0_TICK_HZ             (SystemClock / 2)
    
    
#define ENC_IN_SPI1
//#define ENC_REVERSE_LED
// ENC28J60 I/O pins SPI MAX 10 Mhz !!
#if defined ENC_IN_SPI1
        #define ENC_CS_TRIS                     (TRISBbits.TRISB15)
        #define ENC_CS_IO                       (LATBbits.LATB15)
        //#define ENC_RST_TRIS          (TRISDbits.TRISD15)     // Not connected by default.  It is okay to leave this pin completely unconnected, in which case this macro should simply be left undefined.
        //#define ENC_RST_IO            (PORTDbits.RD15)

        // SPI SCK, SDI, SDO pins are automatically controlled by the
        #define ENC_SPI_IF                      (IFS0bits.SPI1RXIF)
        #define ENC_SSPBUF                      (SPI1BUF)
        #define ENC_SPICON1                     (SPI1CON)
        #define ENC_SPICON1bits         (SPI1CONbits)
        #define ENC_SPIBRG                      (SPI1BRG)
        #define ENC_SPISTATbits         (SPI1STATbits)
#elif defined ENC_IN_SPI2
        #define ENC_CS_TRIS                     (TRISAbits.TRISA0)
        #define ENC_CS_IO                       (LATAbits.LATA0)
        //#define ENC_RST_TRIS          (TRISFbits.TRISF13)     // Not connected by default.  It is okay to leave this pin completely unconnected, in which case this macro should simply be left undefined.
        //#define ENC_RST_IO            (PORTFbits.RF13)

        // SPI SCK, SDI, SDO pins are automatically controlled by the
        // PIC32 SPI module
        #define ENC_SPI_IF                      (IFS1bits.SPI2RXIF)
        #define ENC_SSPBUF                      (SPI2BUF)
        #define ENC_SPICON1                     (SPI2CON)
        #define ENC_SPISTATbits         (SPI2STATbits)
        #define ENC_SPICON1bits         (SPI2CONbits)
        #define ENC_SPIBRG                      (SPI2BRG)
#endif

#define SPIFLASH_CS_TRIS		(TRISBbits.TRISB13)
#define SPIFLASH_CS_IO			(LATBbits.LATB13)
#define SPIFLASH_SCK_TRIS		(TRISBbits.TRISB14)
#define SPIFLASH_SDI_TRIS		(TRISAbits.TRISA1)
#define SPIFLASH_SDI_IO			(PORTAbits.RA1)
#define SPIFLASH_SDO_TRIS		(TRISBbits.TRISB5)
#define SPIFLASH_SPI_IF			(IFS1bits.SPI1RXIF)
#define SPIFLASH_SSPBUF			(SPI1BUF)
#define SPIFLASH_SPICON1		(SPI1CON)
#define SPIFLASH_SPICON1bits	(SPI1CONbits)
#define SPIFLASH_SPISTATbits	(SPI1STATbits)
#define SPIFLASH_SPIBRG			(SPI1BRG)




#ifdef	__cplusplus
}
#endif

#endif	/* HARDWAREPROFILE_H */

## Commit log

2020-09-18 PCB added
    [EtherGeiger.brd, EtherGeiger.sch, io.brd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]
2022-08-10 Fixes in MQTT library
    [MQTT.h]

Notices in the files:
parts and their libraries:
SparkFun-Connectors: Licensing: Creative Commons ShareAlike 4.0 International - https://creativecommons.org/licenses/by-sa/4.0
